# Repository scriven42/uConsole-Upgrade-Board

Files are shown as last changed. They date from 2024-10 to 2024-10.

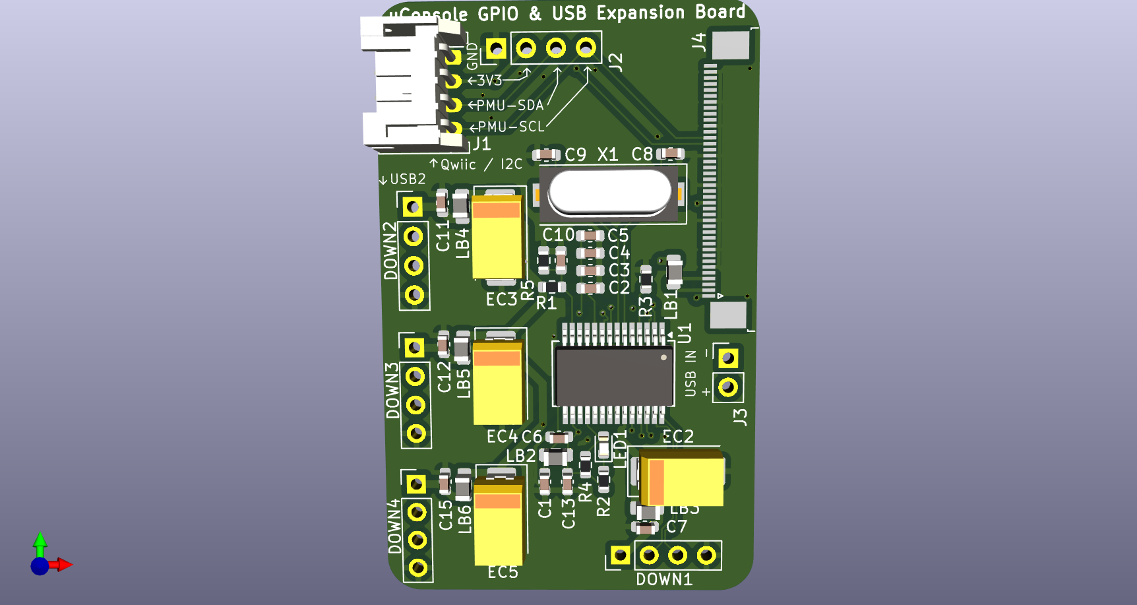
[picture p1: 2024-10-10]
uConsole Upgrade Board, Front.png

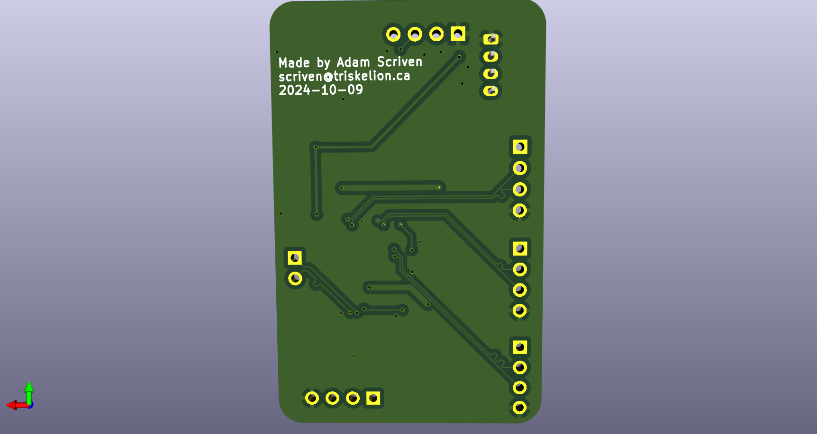
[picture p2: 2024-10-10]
uConsole Upgrade Board, Back.png

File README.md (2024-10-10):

# uConsole-Upgrade-Board

A board to upgrade the uConsole, expanding the GPIO and unused USB with i2c headers and a USB2 hub.

It connects to the 40-pin, 0.5mm pitch GPIO FFC/FPC connector, as well as being soldered to the unallocated USB4 pads. It splits out 3.3V I2C, providing a Qwiic connector (JST-SH) and soldering headers, and also provides a GL850-based USB2 Hub, the 4 ports accessible by soldering headers.

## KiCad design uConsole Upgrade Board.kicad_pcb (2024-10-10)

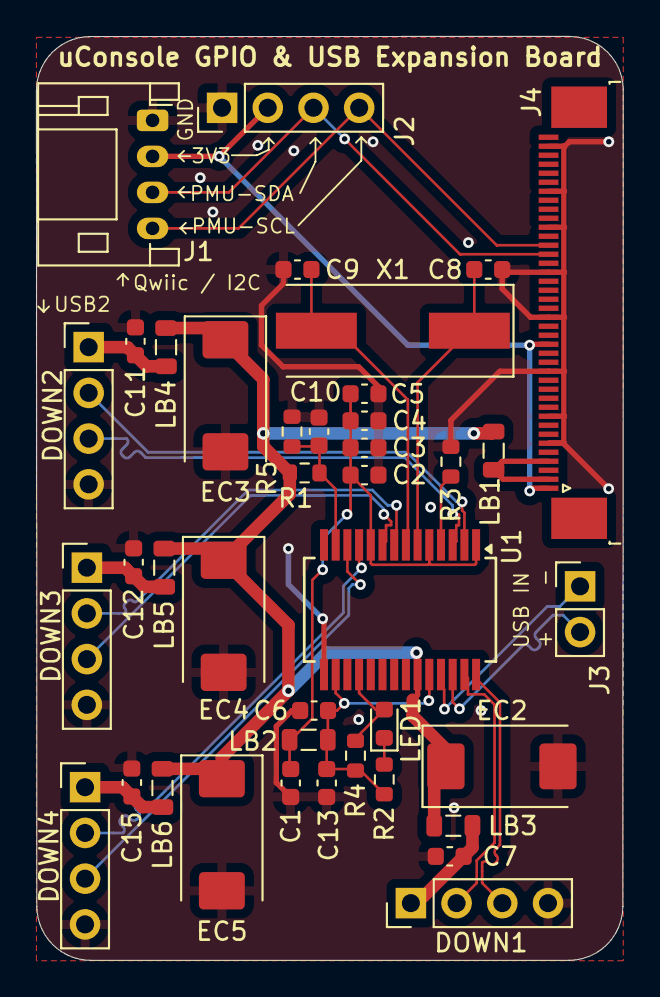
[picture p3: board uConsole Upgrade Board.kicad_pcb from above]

Board: 4 copper layers, 32.6 x 51.3 mm, 40 parts (0 on the bottom side), 28 nets.

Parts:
C1: 1uF; C_0603_1608Metric
C2, C3, C4, C5, C6, C7, C10, C11, C12, C15: 0.1uF; C_0603_1608Metric
C8, C9: 20P; C_0603_1608Metric
C13: 10uF; C_0603_1608Metric
DOWN1, DOWN2, DOWN3, DOWN4: USBA-A; PinHeader_1x04_P2.54mm_Vertical
EC2, EC3, EC4, EC5: 100uF; CP_EIA-7343-31_Kemet-D
J1: Conn_01x04_Pin; JST_PH_S4B-PH-K_1x04_P2.00mm_Horizontal
J2: Conn_01x04_Pin; PinHeader_1x04_P2.54mm_Vertical
J3: Conn_01x02_Pin; PinHeader_1x02_P2.54mm_Vertical
J4: Conn_01x40; TE_4-1734839-0_1x40-1MP_P0.5mm_Horizontal
LB1, LB2, LB3, LB4, LB5, LB6: FB; L_0805_2012Metric
LED1: PWR_LED; LED_0603_1608Metric
R1: 10K; R_0603_1608Metric
R2: 470R; R_0603_1608Metric
R3: 680R 1%; R_0603_1608Metric
R4: 100K; R_0603_1608Metric
R5: 47K; R_0603_1608Metric
U1: GL850AUSB; SSOP-28_5.3x10.2mm_P0.65mm
X1: 12MHz; Crystal_SMD_HC49-SD

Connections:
+3.3V: J1.2, J2.2, J4.1, J4.17
+5V: J4.2, J4.4, LB1.1
/GL850G-USB2.0-HUB/PGANG: LED1.2, R4.1, U1.18 (PGANG)
/GL850G-USB2.0-HUB/RESET#: C10.2, R1.1, R5.2, U1.13 (RESET#)
/GL850G-USB2.0-HUB/RREF: R3.2, U1.4 (RREF)
/GL850G-USB2.0-HUB/USB_D1+: DOWN1.3 (D+), U1.28 (DP1)
/GL850G-USB2.0-HUB/USB_D1-: DOWN1.2 (D-), U1.27 (DM1)
/GL850G-USB2.0-HUB/USB_D2+: DOWN2.3 (D+), U1.3 (DP2)
/GL850G-USB2.0-HUB/USB_D2-: DOWN2.2 (D-), U1.2 (DM2)
/GL850G-USB2.0-HUB/USB_D3+: DOWN3.3 (D+), U1.9 (DP3)
/GL850G-USB2.0-HUB/USB_D3-: DOWN3.2 (D-), U1.8 (DM3)
/GL850G-USB2.0-HUB/USB_D4+: DOWN4.3 (D+), U1.12 (DP4)
/GL850G-USB2.0-HUB/USB_D4-: DOWN4.2 (D-), U1.11 (DM4)
/GL850G-USB2.0-HUB/X1: C8.2, U1.6 (XTAL1), X1.1
/GL850G-USB2.0-HUB/X2: C9.2, U1.7 (XTAL2), X1.2
/GPIO0: J1.3, J2.3, J4.27
/GPIO1: J1.4, J2.4, J4.28
/USB_D_IN+: J3.2, U1.26 (DP0)
/USB_D_IN-: J3.1, U1.25 (DM0)
AVDD: C1.2, C2.2, C3.2, C4.2, C5.2, LB2.1, U1.1 (AVDD1), U1.5 (AVDD2), U1.10 (AVDD3)
DVDD: C6.2, C13.2, LB2.2, R2.2, R4.2, U1.16 (DVDD), U1.24 (V33)
GND: C1.1, C2.1, C3.1, C4.1, C5.1, C6.1, C7.1, C8.1, C9.1, C10.1, C11.1, C12.1, C13.1, C15.1, DOWN1.4 (GND), DOWN2.4 (GND), DOWN3.4 (GND), DOWN4.4 (GND), EC2.2, EC3.2, EC4.2, EC5.2, J1.1, J2.1, J4.6, J4.9, J4.14, J4.20, J4.25, J4.30, J4.34, J4.39, R3.1, R5.1, U1.15 (GND)
unnamed: C7.2, DOWN1.1 (VCC), LB3.1
unnamed: C11.2, DOWN2.1 (VCC), LB4.1
unnamed: C12.2, DOWN3.1 (VCC), LB5.1
unnamed: C15.2, DOWN4.1 (VCC), LB6.1
unnamed: LED1.1, R2.1
VCC: EC2.1, EC3.1, EC4.1, EC5.1, LB1.2, LB3.2, LB4.2, LB5.2, LB6.2, R1.2, U1.23 (V5)
